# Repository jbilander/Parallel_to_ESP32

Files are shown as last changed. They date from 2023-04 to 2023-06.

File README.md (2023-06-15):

# Parallel_to_ESP32
A parallel to ESP32 project for the Amiga

***

This carrier board is made to host the popular ESP32-DEVKIT-V1 board widely available for a few bucks on AliExpress and the likes. Powering the board can be done by taking +5V from the Amigas external floppy drive port using an [Adapter](https://github.com/jbilander/Amiga_DB23_to_USB_C_power_only_adapter) and connect to the DEVKIT's Micro-USB jack.

A FileServer firmware is being developed and is available here:<br />
https://github.com/jbilander/ESP32-FileServer

***
<a href="https://i.imgur.com/PKCFaCk.jpg">

</a>
<a href="https://i.imgur.com/8DI33Nv.jpg">

</a>
<a href="https://i.imgur.com/IpKCfs6.jpg">

</a>
<br />
<a href="https://i.imgur.com/Da3Olv3.jpg">

</a>

***

Revision 1A
<br />
<a href="images/Parallel_to_ESP32_pic1.png">
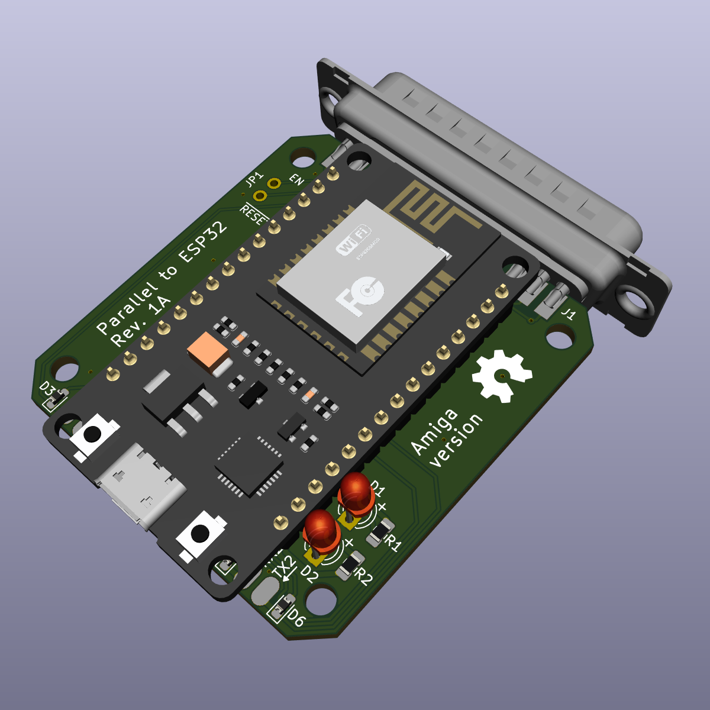
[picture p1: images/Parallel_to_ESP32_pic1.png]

</a>
<br />
<a href="images/Parallel_to_ESP32_pic2.png">
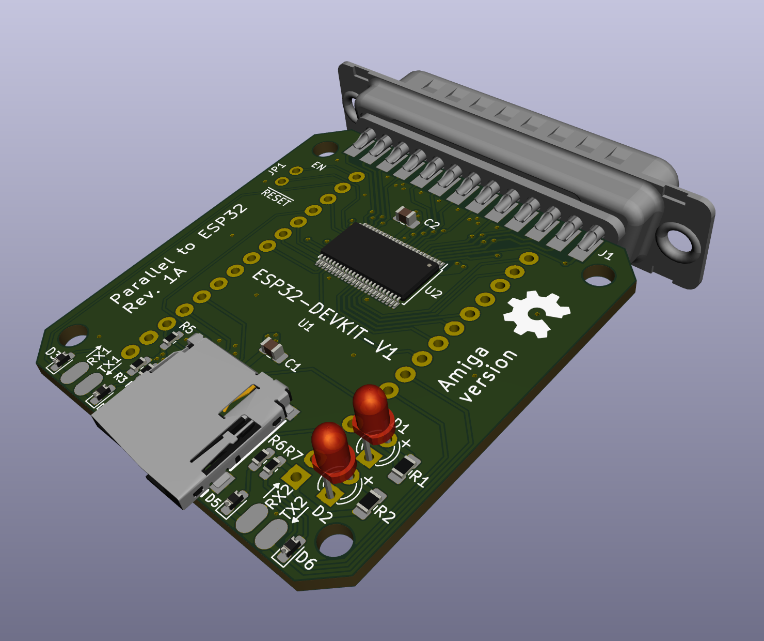
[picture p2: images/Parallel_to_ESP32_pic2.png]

</a>
<a href="images/Parallel_to_ESP32_pic3.png">
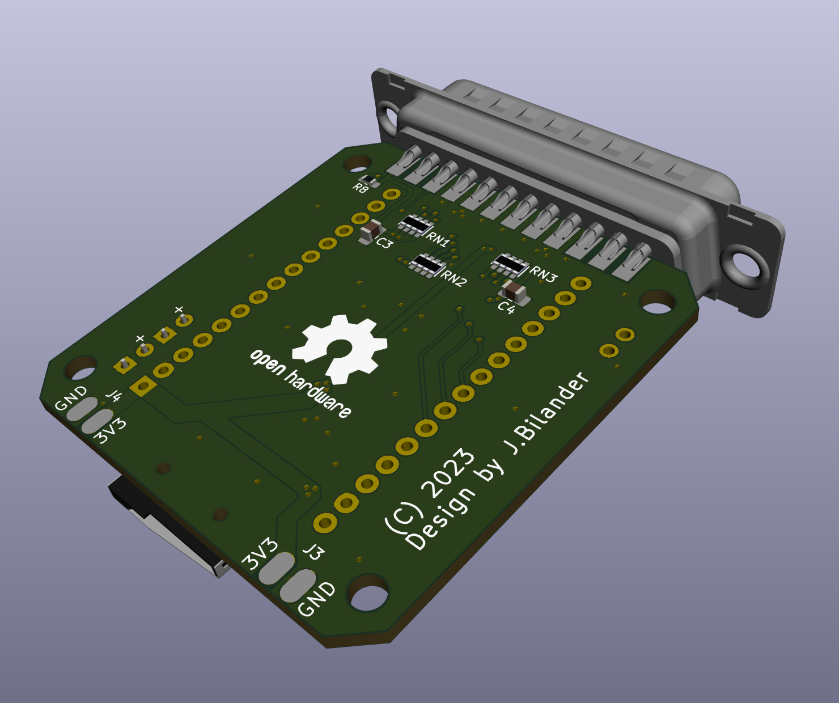
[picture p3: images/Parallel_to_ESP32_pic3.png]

</a>
<br />
<a href="images/Parallel_to_ESP32_pic4.png">
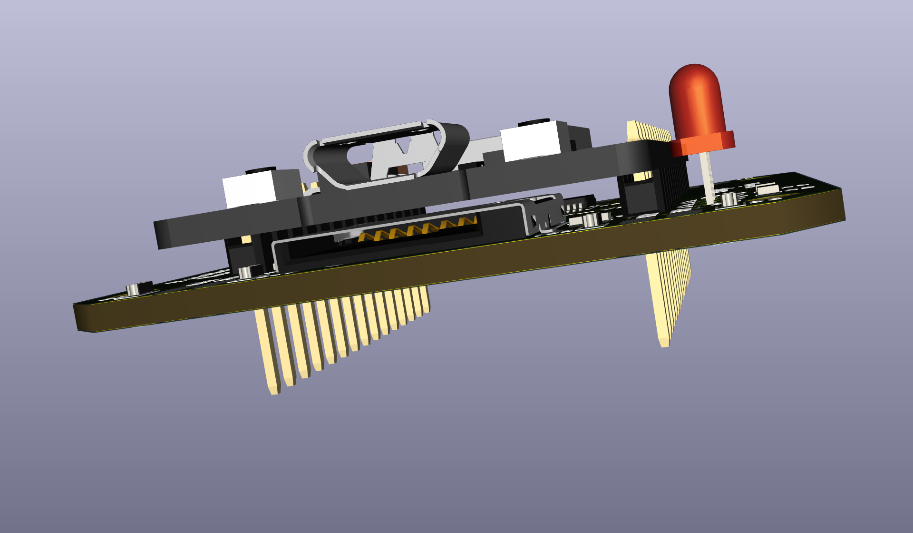
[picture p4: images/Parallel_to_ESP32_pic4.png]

</a>
<br />
<a href="images/Parallel_to_ESP32_pic5.png">
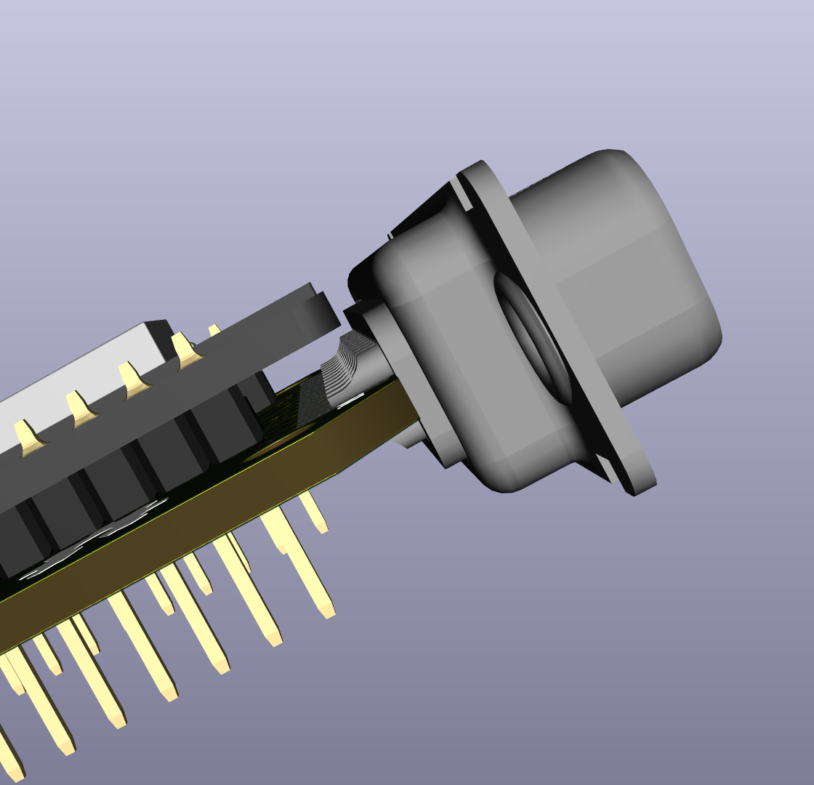
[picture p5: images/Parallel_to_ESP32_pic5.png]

</a>

***

BOM Rev. 1A
---------
Designator  | Name/Value   | Package | Notes
-|-|-|-|
U1 | ESP32-DEVKIT-V1 | DIP-30 | Please note tested variant is Type/Color: <br />[ESP32-CP2102-MICRO](https://www.aliexpress.com/item/1005004337178335.html)
U2 | SN74CB3T16210DGGR | TSSOP-48  | [SN74CB3T16210DGGR](https://www.mouser.com/ProductDetail/595-SN74CB3T16210DGG)
J1 | D-Sub DB25 Male connector | EdgeMount, parallel port connector solder type | [D-Sub DB25M](https://www.aliexpress.com/item/32974759586.html)
J2 | Sunrom Micro SD Card Holder | 9-pin Micro SD card slot connector | [Sunrom Micro-SD card holder](https://www.aliexpress.com/item/32802051702.html)
J3 | PinHeader 2x02 | EdgeMount, PinHeader_2x02_P2.54mm | UART1 connector PADs with 3V3/GND Power connectors on the underside for external powering a [RS-232 device](https://www.aliexpress.com/item/1005001685534114.html) or similar from the ESP32
J4 | PinHeader 2x02 | EdgeMount, PinHeader_2x02_P2.54mm | UART2 connector PADs with 3V3/GND Power connectors on the underside for external powering a [RS-232 device](https://www.aliexpress.com/item/1005001685534114.html) or similar from the ESP32
R1 | ~150 Ω Resistor | 0805, 200 mW | (Mandatory if D1 populated) Series resistor for D1 LED, adjust R-value to your type of LED and preferred brightness
R2 | ~150 Ω Resistor | 0805, 200 mW | (Mandatory if D2 populated) Series resistor for D2 LED, adjust R-value to your type of LED and preferred brightness
R3,R4,R6,R7 | LED Resistor 1k Ω | 0603 | [RC0603FR-071KL](https://www.mouser.com/ProductDetail/603-RC0603FR-071KL)
R5 | Resistor 10k or 4.7k Ω | 0603 | Pull-up resistor for Card Present/Detect, signal grounded when card is present in socket
R8 | Resistor 4.7k Ω or 10k Ω | 0603 | Pull-up resistor (on 5V side) for /STROBE-signal <br />[RC0603FR-074K7L](https://www.mouser.com/ProductDetail/603-RC0603FR-074K7L)
RN1-RN3 | CAY16-4701F4LF Resistor pack 4.7k or 10k Ω (CAY16-103J4LF) | 1206 | [CAY16-4701F4LF](https://www.mouser.com/ProductDetail/652-CAY16A-4701F4LF) Optional Pull-up resistors for Signals: ACK,BUSY,POUT,SELECT,Data0-Data7
D1 (Optional) | LED 3mm | PinHeader_1x02_P2.54mm_Vertical, pin pitch 2.54 mm | [Activity LED indicator](https://www.aliexpress.com/item/1005001688927024.html) (Diffused Orange / Amber or whatever colour you prefer)
D2 (Optional) | LED 3mm | PinHeader_1x02_P2.54mm_Vertical, pin pitch 2.54 mm | [Power LED indicator](https://www.aliexpress.com/item/1005001688927024.html) (Green Diffused or whatever colour you prefer)
D3-D6 | SMD LED | 0603 | [SMD LED 0603](https://www.aliexpress.com/item/1005003836509392.html)
C1-C4 | Capacitor 0.1uF = 100nF | 0805 |
JP1 (Optional) | PinHeader 1x02 | PinHeader_1x02_P2.54mm_Vertical | Shunt on to enable reset ESP32 in conjunction with Ctrl-Amiga-Amiga, Please Note pressing the RESET-button on the ESP32 will also assert the Amiga-RESET, be careful, know what you're doing if you enable this one.

***

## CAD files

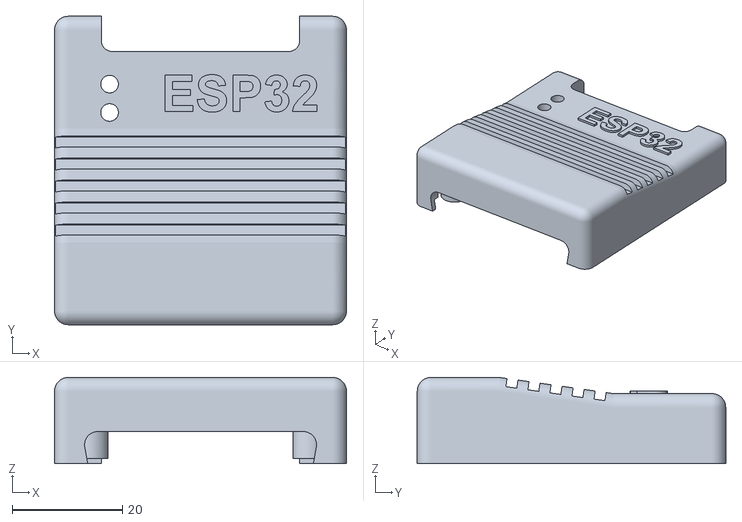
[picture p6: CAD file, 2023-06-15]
3D/Parallel_to_ESP32_case_top.stl
53.0 x 56.0 x 15.6

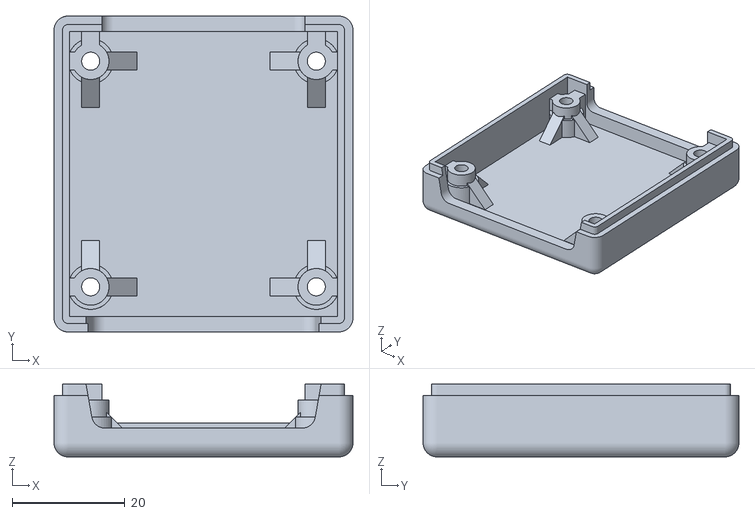
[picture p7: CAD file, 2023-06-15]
3D/Parallel_to_ESP32_case_bottom.stl
53.0 x 56.0 x 12.9

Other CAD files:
3D/Parallel_to_ESP32_text.skp

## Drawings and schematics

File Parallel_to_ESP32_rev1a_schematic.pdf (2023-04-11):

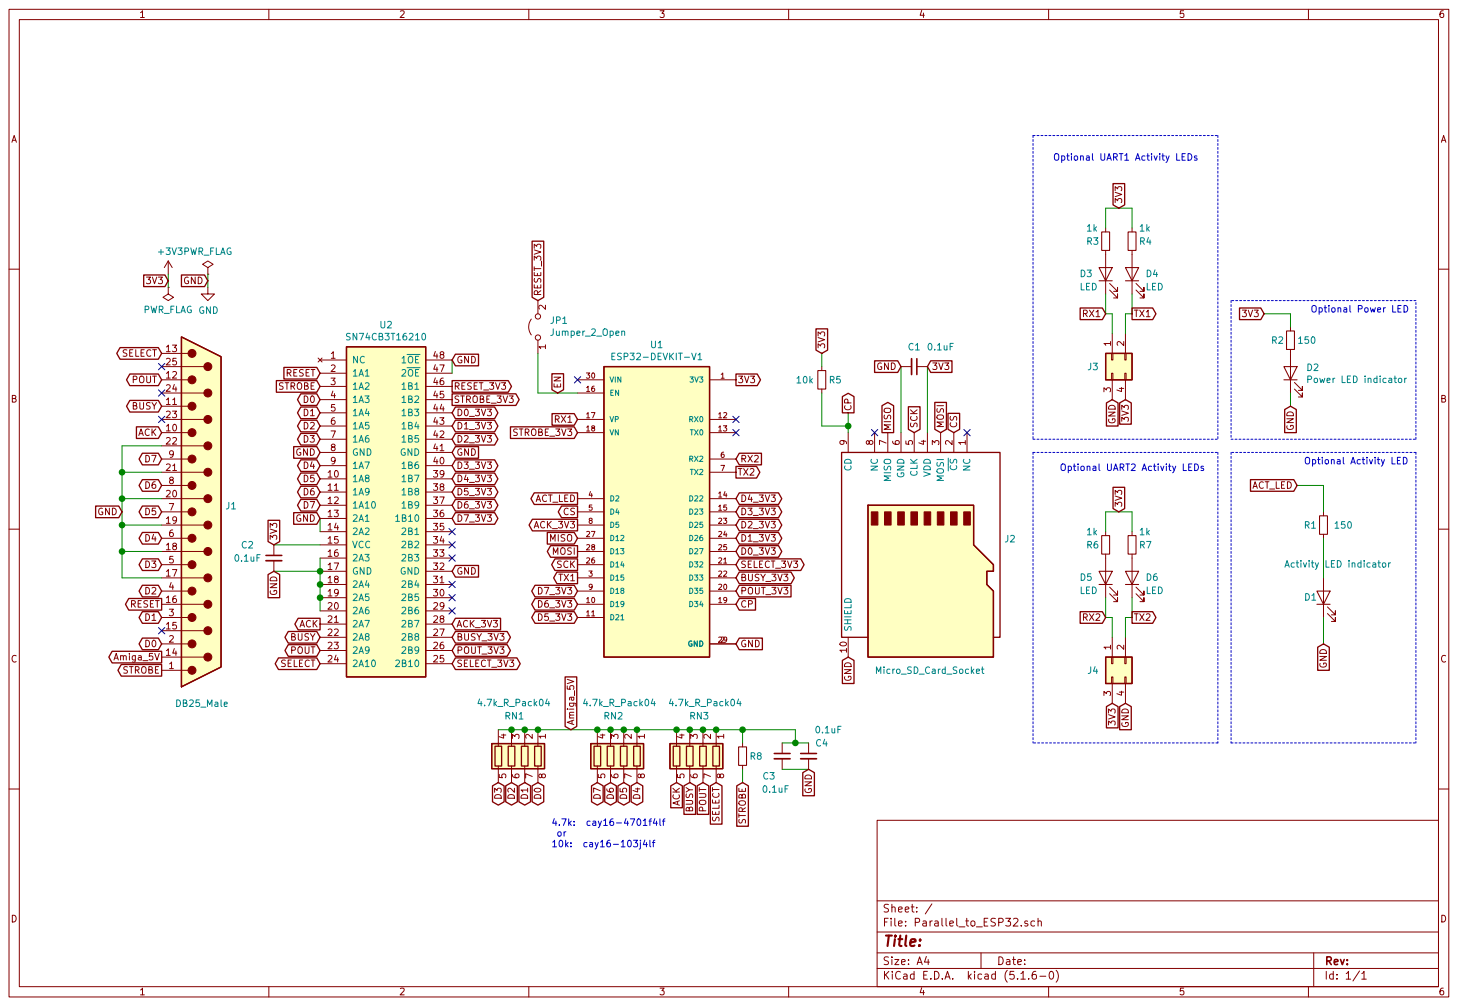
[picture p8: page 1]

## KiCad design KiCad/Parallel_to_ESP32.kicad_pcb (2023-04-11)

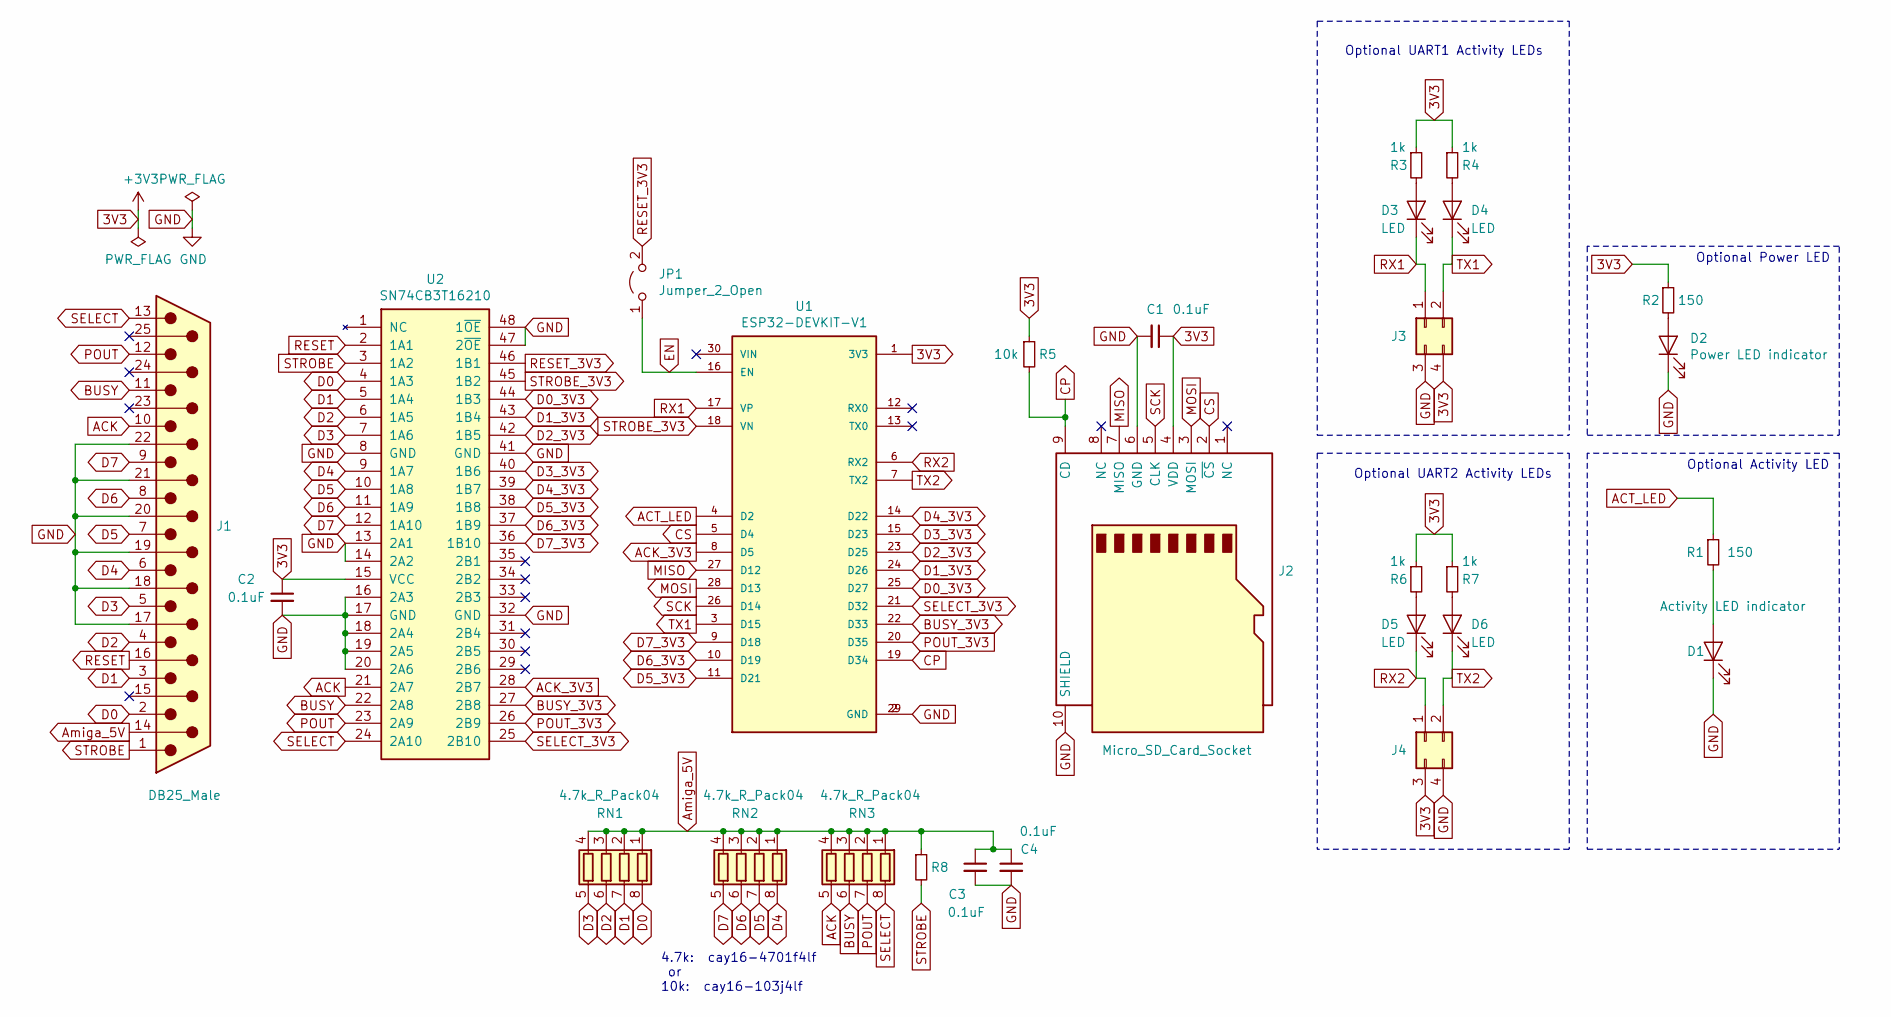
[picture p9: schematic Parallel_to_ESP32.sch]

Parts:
C1, C2, C3, C4: 0.1uF; C_0805_2012Metric_Pad1.15x1.40mm_HandSolder
D1: Activity LED indicator; LED_D3.0mm
D2: Power LED indicator; LED_D3.0mm
D3, D4, D5, D6: LED; D_0603_1608Metric_Pad1.05x0.95mm_HandSolder
J1: DB25_Male; DSUB-25_Male_EdgeMount_P2.77mm
J2: Micro_SD_Card_Socket; GCT-MEM2055-00-190-01-A
J3, J4: Conn_02x02_Top_Bottom; PinHeader_2x02_P2.54mm_EdgeMount_SMD
JP1: Jumper_2_Open; PinHeader_1x02_P2.54mm_Vertical
R1, R2: 150; R_0805_2012Metric_Pad1.15x1.40mm_HandSolder
R3, R4, R6, R7: 1k; R_0603_1608Metric_Pad1.05x0.95mm_HandSolder
R5, R8: 10k; R_0603_1608Metric_Pad1.05x0.95mm_HandSolder
RN1, RN2, RN3: 4.7k_R_Pack04; RESCAF80P320X160X60-8N
U1: ESP32-DEVKIT-V1; MODULE_ESP32_DEVKIT_V1; PARTREV N/A
U2: SN74CB3T16210; TSSOP-48_6.1x12.5mm_P0.5mm

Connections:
3V3: C1.1, C2.1, J2.4 (VDD), J3.4, J4.3, R2.1, R3.1, R4.1, R5.1, R6.1, R7.1, U1.1 (3V3), U2.15 (VCC)
ACK: J1.10, RN3.5 (R4.2), U2.21 (2A7)
ACK_3V3: U1.8 (D5), U2.28 (2B7)
ACT_LED: R1.1, U1.4 (D2)
Amiga_5V: C3.1, C4.1, J1.14, R8.1, RN1.1 (R1.1), RN1.2 (R2.1), RN1.3 (R3.1), RN1.4 (R4.1), RN2.1 (R1.1), RN2.2 (R2.1), RN2.3 (R3.1), RN2.4 (R4.1), RN3.1 (R1.1), RN3.2 (R2.1), RN3.3 (R3.1), RN3.4 (R4.1)
BUSY: J1.11, RN3.6 (R3.2), U2.22 (2A8)
BUSY_3V3: U1.22 (D33), U2.27 (2B8)
CP: J2.9 (CD), R5.2, U1.19 (D34)
CS: J2.2 (~CS), U1.5 (D4)
D0: J1.2, RN1.8 (R1.2), U2.4 (1A3)
D0_3V3: U1.25 (D27), U2.44 (1B3)
D1: J1.3, RN1.7 (R2.2), U2.5 (1A4)
D1_3V3: U1.24 (D26), U2.43 (1B4)
D2: J1.4, RN1.6 (R3.2), U2.6 (1A5)
D2_3V3: U1.23 (D25), U2.42 (1B5)
D3: J1.5, RN1.5 (R4.2), U2.7 (1A6)
D3_3V3: U1.15 (D23), U2.40 (1B6)
D4: J1.6, RN2.8 (R1.2), U2.9 (1A7)
D4_3V3: U1.14 (D22), U2.39 (1B7)
D5: J1.7, RN2.7 (R2.2), U2.10 (1A8)
D5_3V3: U1.11 (D21), U2.38 (1B8)
D6: J1.8, RN2.6 (R3.2), U2.11 (1A9)
D6_3V3: U1.10 (D19), U2.37 (1B9)
D7: J1.9, RN2.5 (R4.2), U2.12 (1A10)
D7_3V3: U1.9 (D18), U2.36 (1B10)
EN: JP1.1 (A), U1.16 (EN)
GND: C1.2, C2.2, C3.2, C4.2, D1.1 (K), D2.1 (K), J1.17, J1.18, J1.19, J1.20, J1.21, J1.22, J2.6 (GND), J2.10 (SHIELD), J3.3, J4.4, U1.2 (GND), U1.29 (GND), U2.8 (GND), U2.13 (2A1), U2.14 (2A2), U2.16 (2A3), U2.17 (GND), U2.18 (2A4), U2.19 (2A5), U2.20 (2A6), U2.32 (GND), U2.41 (GND), U2.47 (2~OE), U2.48 (1~OE)
MISO: J2.7 (MISO), U1.27 (D12)
MOSI: J2.3 (MOSI), U1.28 (D13)
unnamed: D1.2 (A), R1.2
unnamed: D2.2 (A), R2.2
unnamed: D3.2 (A), R3.2
unnamed: D4.2 (A), R4.2
unnamed: D5.2 (A), R6.2
unnamed: D6.2 (A), R7.2
POUT: J1.12, RN3.7 (R2.2), U2.23 (2A9)
POUT_3V3: U1.20 (D35), U2.26 (2B9)
RESET: J1.16, U2.2 (1A1)
RESET_3V3: JP1.2 (B), U2.46 (1B1)
RX1: D3.1 (K), J3.1, U1.17 (VP)
RX2: D5.1 (K), J4.1, U1.6 (RX2)
SCK: J2.5 (CLK), U1.26 (D14)
SELECT: J1.13, RN3.8 (R1.2), U2.24 (2A10)
SELECT_3V3: U1.21 (D32), U2.25 (2B10)
STROBE: J1.1, R8.2, U2.3 (1A2)
STROBE_3V3: U1.18 (VN), U2.45 (1B2)
TX1: D4.1 (K), J3.2, U1.3 (D15)
TX2: D6.1 (K), J4.2, U1.7 (TX2)

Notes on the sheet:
Optional Activity LED
Optional Power LED
Optional UART1 Activity LEDs
Optional UART2 Activity LEDs
4.7k: cay16-4701f4lf or 10k: cay16-103j4lf

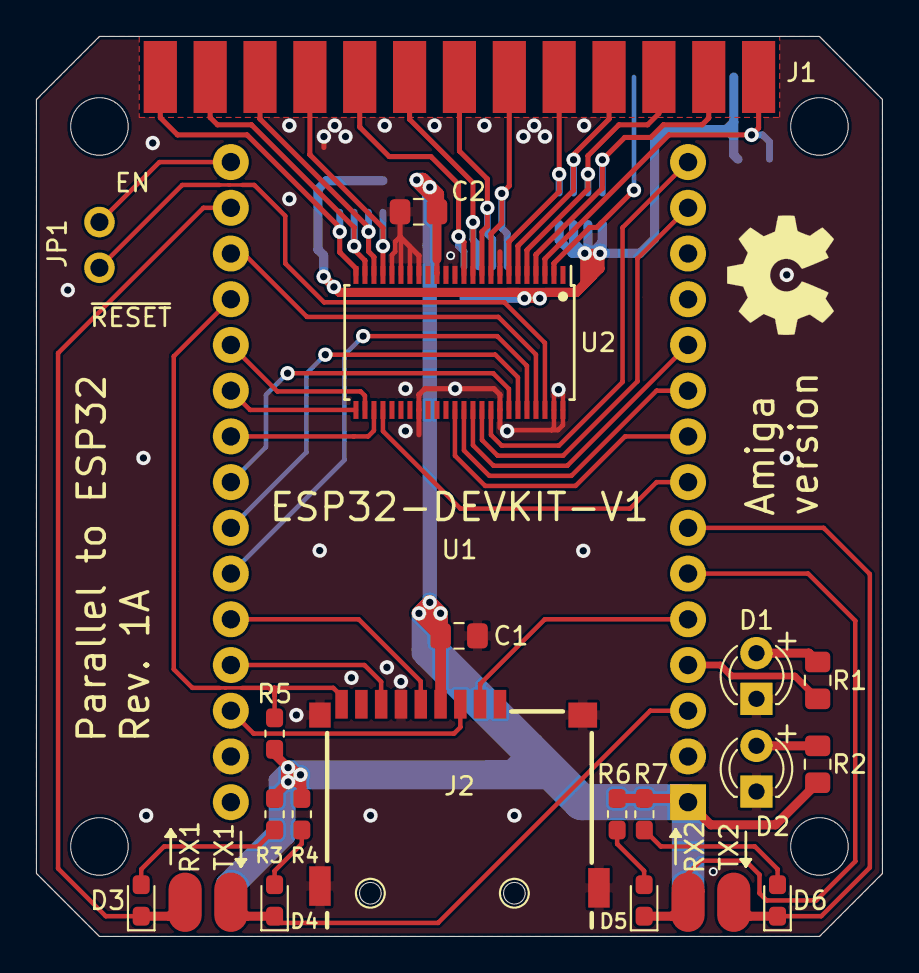
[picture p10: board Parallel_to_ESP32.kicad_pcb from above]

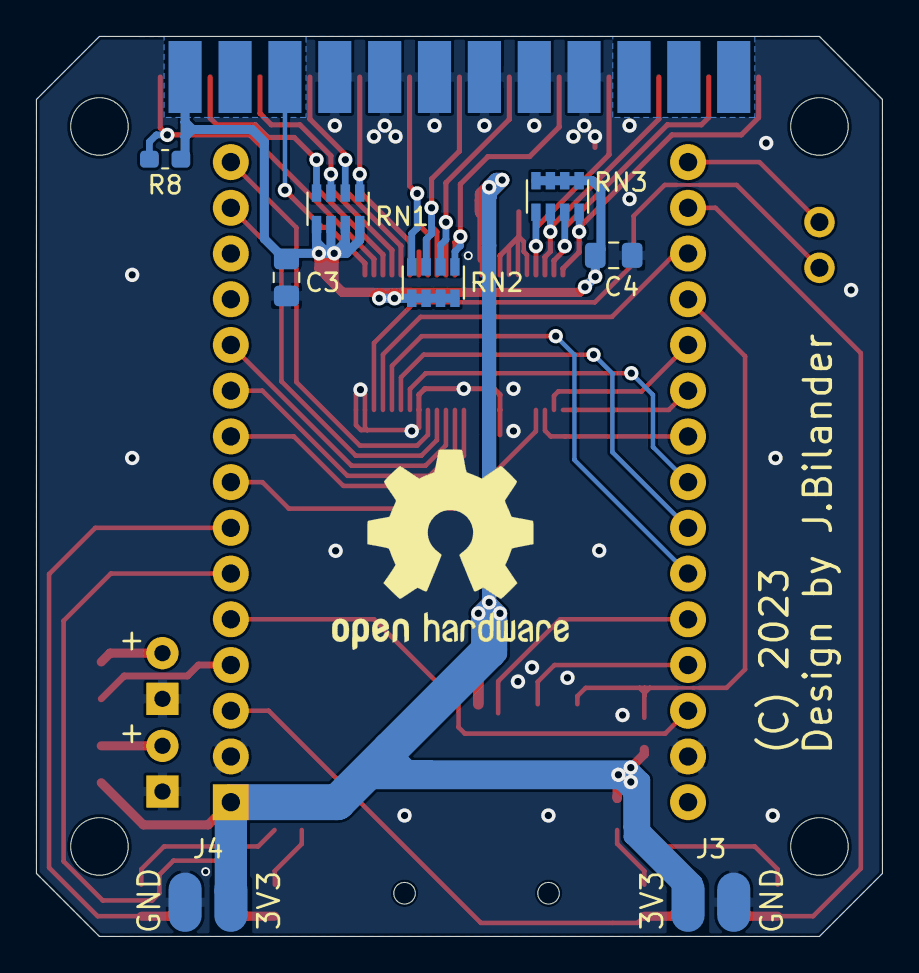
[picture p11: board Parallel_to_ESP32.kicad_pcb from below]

Board: 2 copper layers, 47.0 x 50.0 mm, 28 parts (6 on the bottom side), 48 nets.

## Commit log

2023-04-02 Added KiCAD-files
    [Parallel_to_ESP32.kicad_pcb, Parallel_to_ESP32.sch]
2023-04-03 placing of components and some routing done
    [Parallel_to_ESP32.kicad_pcb, Parallel_to_ESP32.sch]
2023-04-03 more routing done
    [Parallel_to_ESP32.kicad_pcb, Parallel_to_ESP32.sch]
2023-04-03 Added Schematic for ESP32 Devkit V1 (DOIT)
2023-04-03 more pin assignments and routing
    [Parallel_to_ESP32.kicad_pcb, Parallel_to_ESP32.sch]
2023-04-04 Added pinheader for UART1
    [Parallel_to_ESP32.kicad_pcb, Parallel_to_ESP32.sch]
2023-04-04 Added pinheader for UART2
    [Parallel_to_ESP32.kicad_pcb, Parallel_to_ESP32.sch]
2023-04-05 Changed R2 resistor to 0805-footprint and did some routing fixes
    [Parallel_to_ESP32.kicad_pcb, Parallel_to_ESP32.sch]
2023-04-05 fixed activity LED circuit using a PNP-transistor
    [Parallel_to_ESP32.kicad_pcb, Parallel_to_ESP32.sch]
2023-04-06 Re-assignment of some pins and simplified Activity LED circuit
    [Parallel_to_ESP32.kicad_pcb, Parallel_to_ESP32.sch]
2023-04-06 Added jumper JP1 for RESET-signal (optional)
    [Parallel_to_ESP32.kicad_pcb, Parallel_to_ESP32.sch]
2023-04-06 Added footprint
2023-04-06 Changed to surface mount footprint for UART1 and UART2 and 3V3/GND on underside, changed JP1 to regular PinHeader P2.54mm
    [Parallel_to_ESP32.kicad_pcb, Parallel_to_ESP32.sch]
2023-04-08 Added optional pull-up resistor packs for all Parallel-port-signals pulled up by Amigas 5V (pin 14)
    [Parallel_to_ESP32.kicad_pcb, Parallel_to_ESP32.sch]
2023-04-08 Added 3D-models
    [Parallel_to_ESP32.kicad_pcb]
2023-04-08 Added 3D-model for ESP32-DEVKIT-V1
    [Parallel_to_ESP32.kicad_pcb]
2023-04-11 Added OSHW-silkscreen logos
    [Parallel_to_ESP32.kicad_pcb]
2023-04-11 Added 3D-model for D-sub DB25 male connector
2023-04-11 Added 3D-model of DB25 to the design
    [Parallel_to_ESP32.kicad_pcb]
2023-04-11 Changed pull-up resistor packs to value 4.7k (cay16-4701f4lf)
    [Parallel_to_ESP32.kicad_pcb, Parallel_to_ESP32.sch]
2023-04-11 Rev1A schematic pdf

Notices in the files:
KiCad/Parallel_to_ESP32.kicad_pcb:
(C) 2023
